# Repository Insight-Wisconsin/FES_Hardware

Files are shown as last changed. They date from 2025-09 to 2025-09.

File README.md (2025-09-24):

# FES_Hardware
Insight Wisconsin's FES R&amp;D team KiCad files

# Required Software:
**KiCad:** PCB layout and design software  
https://www.kicad.org/download/ (Select your OS and then the Github download)
 
**Git:** Version control software  
https://git-scm.com/downloads (Select your OS and then download at the top of the page)

(OPTIONAL)  
**WSL:** Linux command line on Windows  
Run powershell as admin and type wsl --install

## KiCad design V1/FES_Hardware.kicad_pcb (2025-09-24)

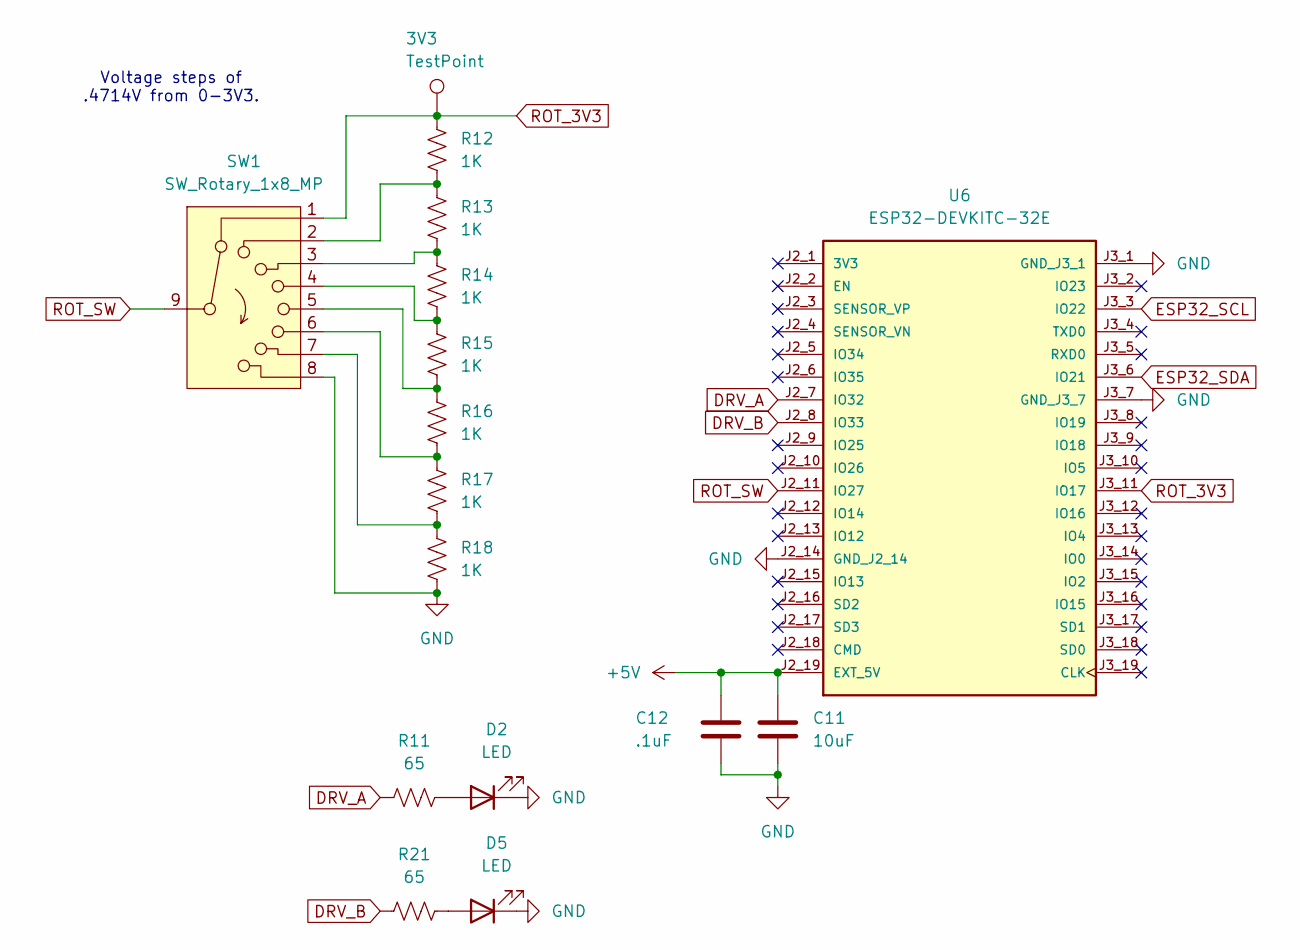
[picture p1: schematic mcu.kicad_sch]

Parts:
3V3: TestPoint; TestPoint_Keystone_5019_Minature
C11: 10uF; C_0805_2012Metric_Pad1.18x1.45mm_HandSolder
C12: .1uF; C_0805_2012Metric_Pad1.18x1.45mm_HandSolder
D2, D5: LED; LED_0805_2012Metric_Pad1.15x1.40mm_HandSolder
R11, R21: 65; R_0805_2012Metric_Pad1.20x1.40mm_HandSolder
R12, R13, R14, R15, R16, R17, R18: 1K; R_0805_2012Metric_Pad1.20x1.40mm_HandSolder
SW1: SW_Rotary_1x8_MP; 2925_ADA
U6: ESP32-DEVKITC-32E; MODULE_ESP32-DEVKITC-32E; PARTREV 1.4

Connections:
+5V: C11.1, C12.1, U6.J2_19 (EXT_5V); also elsewhere on the board
DRV_A: R11.1, U6.J2_7 (IO32); also elsewhere on the board
DRV_B: R21.1, U6.J2_8 (IO33); also elsewhere on the board
ESP32_SCL: U6.J3_3 (IO22); also elsewhere on the board
ESP32_SDA: U6.J3_6 (IO21); also elsewhere on the board
GND: C11.2, C12.2, D2.1 (K), D5.1 (K), R18.2, SW1.8, U6.J2_14 (GND_J2_14), U6.J3_1 (GND_J3_1), U6.J3_7 (GND_J3_7); also elsewhere on the board
unnamed: D2.2 (A), R11.2
unnamed: D5.2 (A), R21.2
unnamed: R12.2, R13.1, SW1.2
unnamed: R13.2, R14.1, SW1.3
unnamed: R14.2, R15.1, SW1.4
unnamed: R15.2, R16.1, SW1.5
unnamed: R16.2, R17.1, SW1.6
unnamed: R17.2, R18.1, SW1.7
ROT_3V3: 3V3.1, R12.1, SW1.1, U6.J3_11 (IO17)
ROT_SW: SW1.9, U6.J2_11 (IO27)

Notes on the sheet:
Voltage steps of .4714V from 0-3V3.

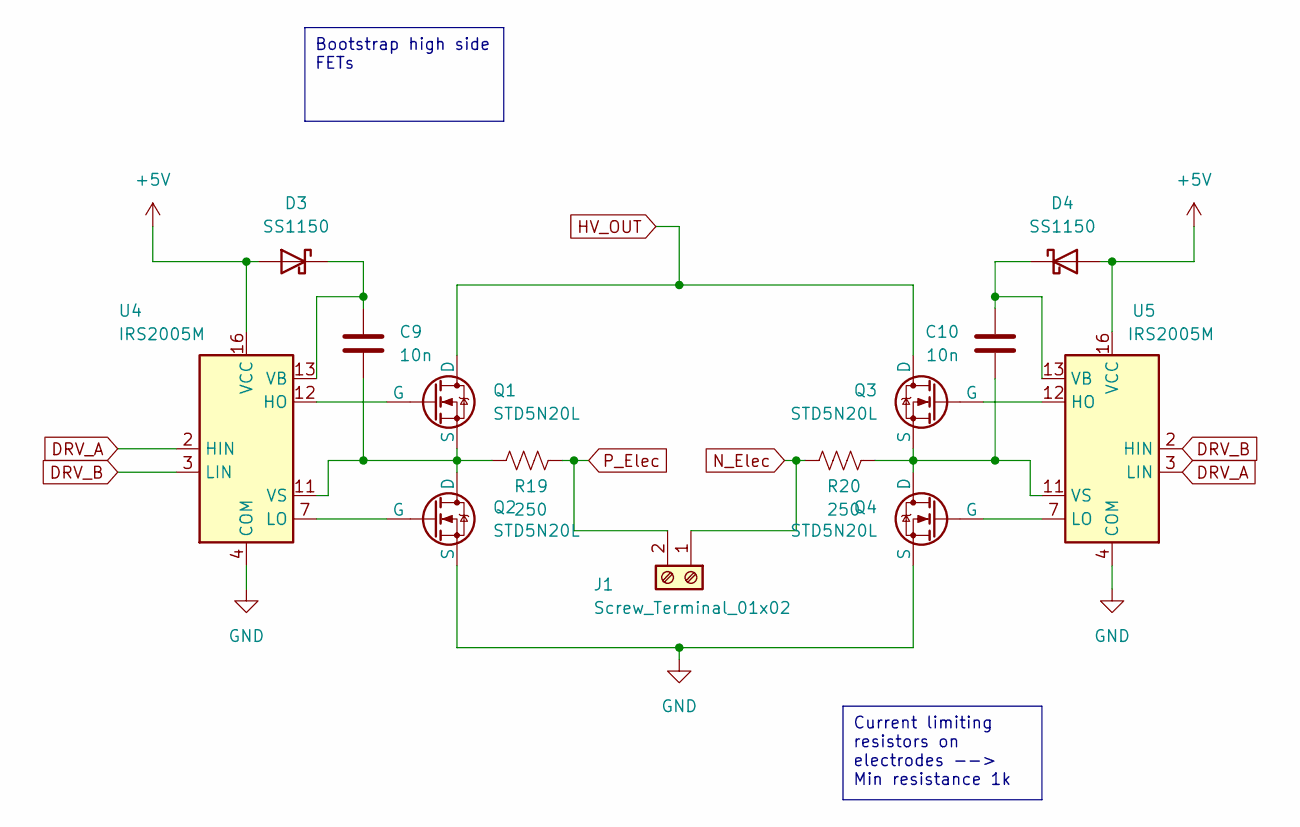
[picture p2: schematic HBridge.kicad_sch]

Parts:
C9, C10: 10n; C_0805_2012Metric_Pad1.18x1.45mm_HandSolder
D3, D4: SS1150; D_SMA
J1: Screw_Terminal_01x02; 691137710002
Q1, Q2, Q3, Q4: STD5N20L; STD5N
R19, R20: 250; R_0805_2012Metric_Pad1.20x1.40mm_HandSolder
U4, U5: IRS2005M; Infineon_MLPQ-16-14-1EP_4x4mm_P0.5mm

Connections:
+5V: D3.2 (A), D4.2 (A), U4.16 (VCC), U5.16 (VCC); also elsewhere on the board
DRV_A: U4.2 (HIN), U5.3 (LIN); also elsewhere on the board
DRV_B: U4.3 (LIN), U5.2 (HIN); also elsewhere on the board
GND: Q2.3 (S), Q4.3 (S), U4.4 (COM), U4.17 (COM), U5.4 (COM), U5.17 (COM); also elsewhere on the board
HV_OUT: Q1.1 (D), Q3.1 (D); also elsewhere on the board
N_Elec: J1.1, R20.1
unnamed: C9.1, D3.1 (K), U4.13 (VB)
unnamed: C10.1, D4.1 (K), U5.13 (VB)
unnamed: Q1.2 (G), U4.12 (HO)
unnamed: C9.2, Q1.3 (S), Q2.1 (D), R19.1, U4.11 (VS)
unnamed: Q2.2 (G), U4.7 (LO)
unnamed: Q3.2 (G), U5.12 (HO)
unnamed: C10.2, Q3.3 (S), Q4.1 (D), R20.2, U5.11 (VS)
unnamed: Q4.2 (G), U5.7 (LO)
P_Elec: J1.2, R19.2

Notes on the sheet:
Bootstrap high side FETs
Current limiting resistors on electrodes --> Min resistance 1k

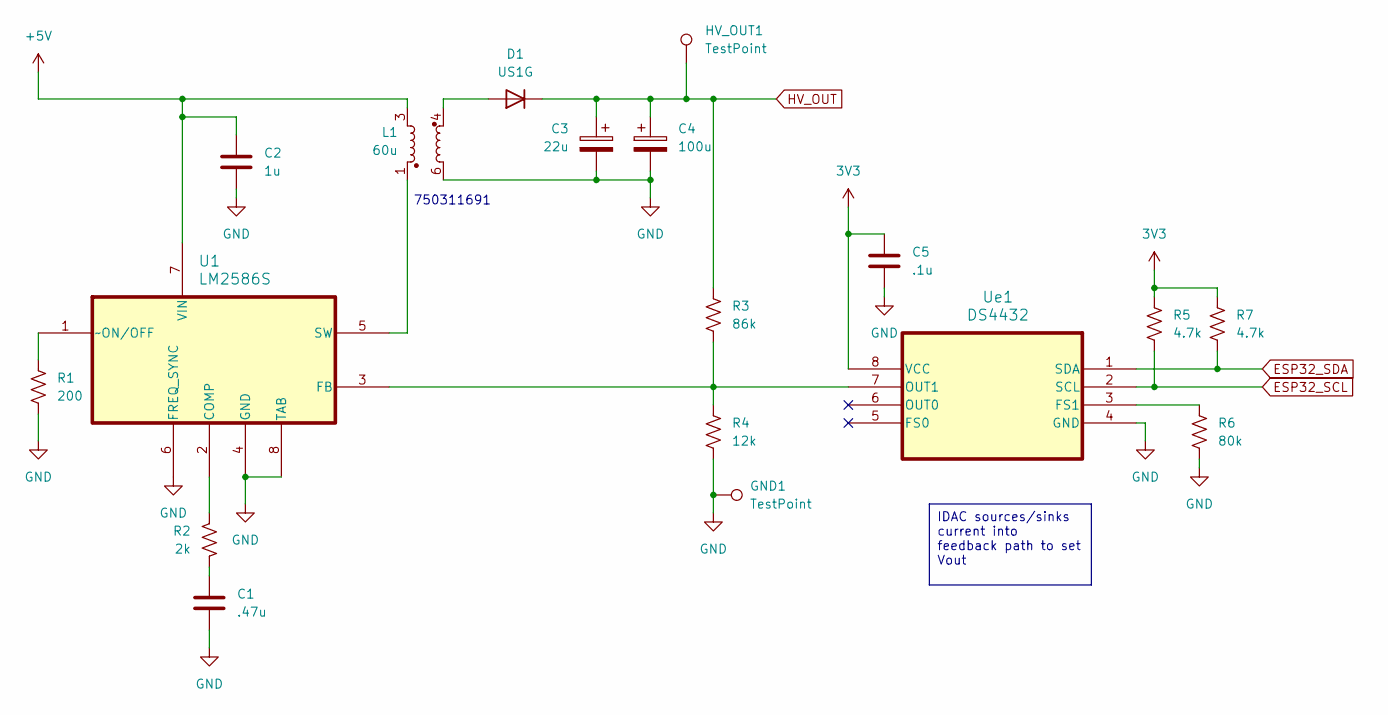
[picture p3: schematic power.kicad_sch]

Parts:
C1: .47u; C_0805_2012Metric_Pad1.18x1.45mm_HandSolder
C2: 1u; C_0805_2012Metric_Pad1.18x1.45mm_HandSolder
C3: 22u; C_0805_2012Metric_Pad1.18x1.45mm_HandSolder
C4: 100u; C_0805_2012Metric_Pad1.18x1.45mm_HandSolder
C5: .1u; C_0805_2012Metric_Pad1.18x1.45mm_HandSolder
D1: US1G; D_SMA
GND1: TestPoint; TestPoint_Keystone_5019_Minature
HV_OUT1: TestPoint; TestPoint_Keystone_5019_Minature
L1: 60u; WE 750311691
R1: 200; R_0805_2012Metric_Pad1.20x1.40mm_HandSolder
R2: 2k; R_0805_2012Metric_Pad1.20x1.40mm_HandSolder
R3: 86k; R_0805_2012Metric_Pad1.20x1.40mm_HandSolder
R4: 12k; R_0805_2012Metric_Pad1.20x1.40mm_HandSolder
R5, R7: 4.7k; R_0805_2012Metric_Pad1.20x1.40mm_HandSolder
R6: 80k; R_0805_2012Metric_Pad1.20x1.40mm_HandSolder
U1: LM2586S; TS7B
Ue1: DS4432; 21-0036_U8&plus_1_MXM

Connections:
3V3: C5.1, R5.1, R7.1, Ue1.8 (VCC)
+5V: C2.1, L1.3, U1.7 (VIN); also elsewhere on the board
ESP32_SCL: R5.2, Ue1.2 (SCL); also elsewhere on the board
ESP32_SDA: R7.2, Ue1.1 (SDA); also elsewhere on the board
GND: C1.2, C2.2, C3.2, C4.2, C5.2, GND1.1, L1.6, R1.2, R4.2, R6.2, U1.4 (GND), U1.6 (FREQ_SYNC), U1.8 (TAB), Ue1.4 (GND); also elsewhere on the board
HV_OUT: C3.1, C4.1, D1.1 (K), HV_OUT1.1, R3.1; also elsewhere on the board
unnamed: C1.1, R2.2
unnamed: D1.2 (A), L1.4
unnamed: R2.1, U1.2 (COMP)
unnamed: R3.2, R4.1, U1.3 (FB), Ue1.7 (OUT1)
unnamed: L1.1, U1.5 (SW)
unnamed: R1.1, U1.1 (~ON/OFF)
unnamed: R6.1, Ue1.3 (FS1)

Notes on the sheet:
IDAC sources/sinks current into feedback path to set Vout
750311691

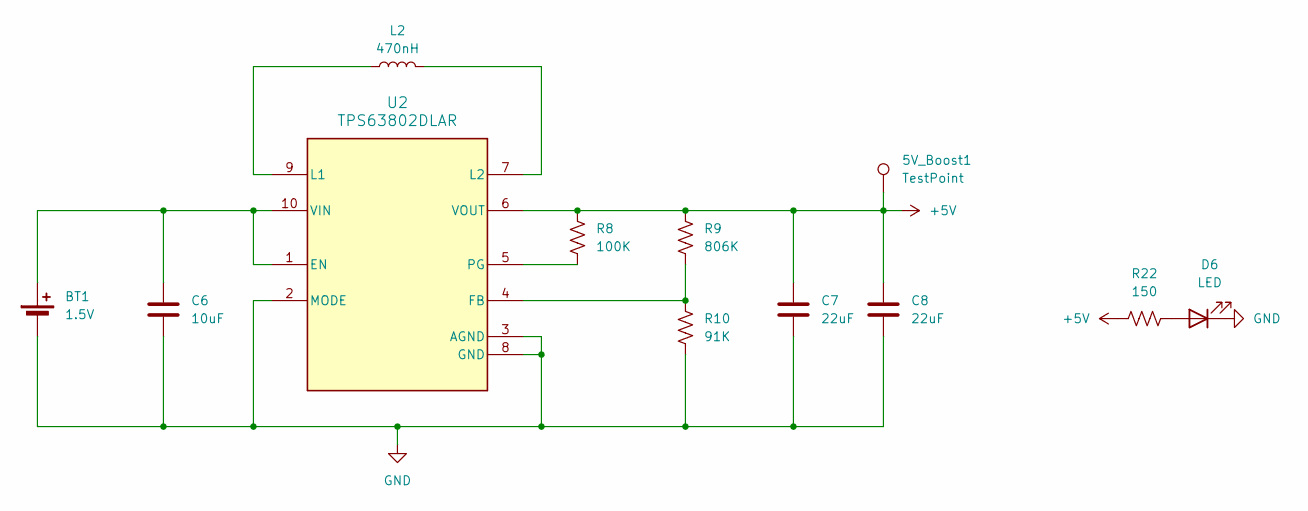
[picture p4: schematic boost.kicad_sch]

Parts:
5V_Boost1: TestPoint; TestPoint_Keystone_5019_Minature
BT1: 1.5V; BatteryHolder_Keystone_2460_1xAA
C6: 10uF; C_0805_2012Metric_Pad1.18x1.45mm_HandSolder
C7, C8: 22uF; C_0805_2012Metric_Pad1.18x1.45mm_HandSolder
D6: LED; LED_0805_2012Metric_Pad1.15x1.40mm_HandSolder
L2: 470nH; INDC2016X120N
R8: 100K; R_0805_2012Metric_Pad1.20x1.40mm_HandSolder
R9: 806K; R_0805_2012Metric_Pad1.20x1.40mm_HandSolder
R10: 91K; R_0805_2012Metric_Pad1.20x1.40mm_HandSolder
R22: 150; R_0805_2012Metric_Pad1.20x1.40mm_HandSolder
U2: TPS63802DLAR; DLA0010A

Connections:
+5V: 5V_Boost1.1, C7.1, C8.1, R8.2, R9.2, R22.1, U2.6 (VOUT); also elsewhere on the board
GND: BT1.2 (-), C6.2, C7.2, C8.2, D6.1 (K), R10.1, U2.2 (MODE), U2.3 (AGND), U2.8 (GND); also elsewhere on the board
unnamed: BT1.1 (+), C6.1, U2.1 (EN), U2.10 (VIN)
unnamed: D6.2 (A), R22.2
unnamed: R9.1, R10.2, U2.4 (FB)
unnamed: L2.1, U2.9 (L1)
unnamed: L2.2, U2.7 (L2)
unnamed: R8.1, U2.5 (PG)

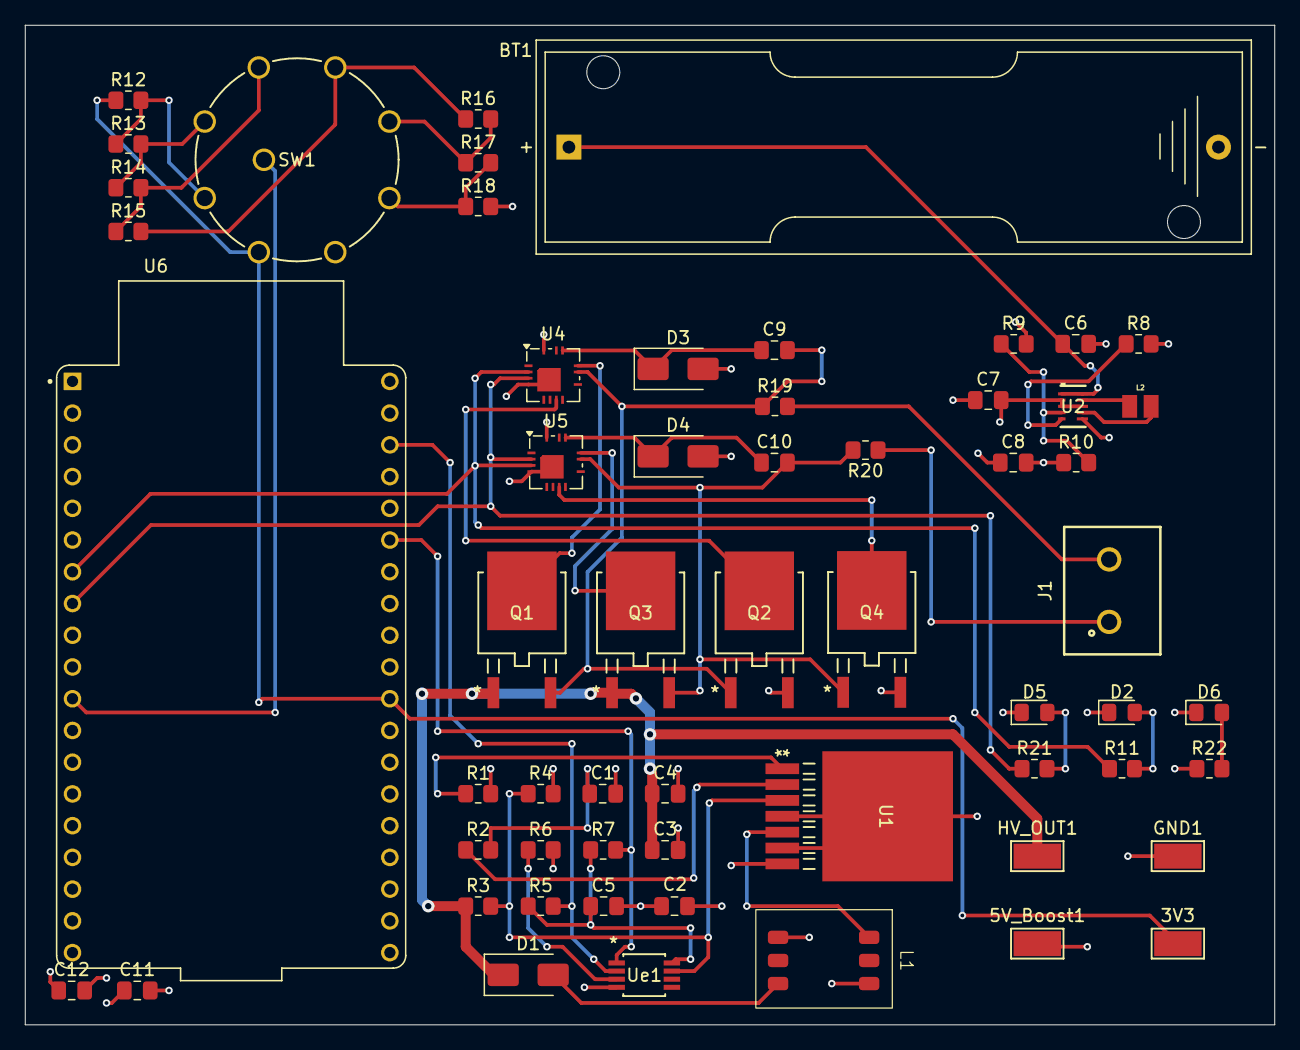
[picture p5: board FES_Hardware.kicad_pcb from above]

Board: 4 copper layers, 100.0 x 80.0 mm, 59 parts (0 on the bottom side), 41 nets.

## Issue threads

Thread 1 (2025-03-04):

Android Studio Documentation

rdrahozal, 2025-03-04:
# Gather any relevant documentation/tutorials on android app development.

**Relevant information may include:**

**XML Documentation:** Android Studio seems to use XML as their UI language. Research and brainstorm UI designs for the app and how to implement them.

**Android Sensor Integration:** Our app will need to get data from the phone's motion sensors. Investigate different APIs and packages that will allow us to do so.

**ESP32 Integration:** We will eventually need our app to communicate with the our ESP32 microcontroller to send electric pulses at the correct time. Research different methods we could achieve this integration/communication.

**Publishing:** Figure out how to publish our app to the Google Play Store.

**PUT ALL RELEVANT FILES OR LINKS IN THIS REPO'S WIKI**
(Make sure to add a relevant title and description)

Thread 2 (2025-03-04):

KiCad Documentation

rdrahozal, 2025-03-04:
# Gather any relevant documentation/tutorials on KiCad development in relation to the project

**Relevant information may include:**

**Working with KiCad:** We will be using KiCad to design and layout our PCBs. Find some documentation/tutorials on using KiCad.

**Working with electrodes:** We will be using electrodes to provide an electrical stimulation to leg muscles. Research different types of electrodes, different ways to integrate and connect them to the microcontroller, and ways to ensure they are safe.

**ESP32 Documentation:** We will be using the ESP32 microcontroller for this project. Research how to implement this microcontroller into a PCB layout, how to connect it, and any software needed to program it.

**PUT ALL RELEVANT FILES OR LINKS IN THIS REPO'S WIKI**
(Make sure to add a relevant title and description)

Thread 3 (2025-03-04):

PCB Design

rdrahozal, 2025-03-04:
# Design the PCB
The PCB will have to house the main components of the hardware side of the FES such as:

**Microcontroller:** Place the microcontroller and and required circuitry. The microcontroller will have to receive power  from the battery and then distribute signals to the electrodes to pulse depending on input from the app.

**Battery:** Implement a battery charging IC to recharge the battery when needed. The battery will have to supply power to the microcontroller and likely electrodes at accurate voltages. May need to implement buck/boost converters to adjust voltages.

**Electrodes:** Design how the electrodes will be connected and powered. Look online for viable electrodes to use and what voltages they require.

**REMEMBER SAFETY IS OUR HIGHEST PRIORITY**

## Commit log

2025-03-04 Initialized KiCad Project
    [FES_Hardware.kicad_pcb, FES_Hardware.kicad_sch]
2025-03-19 created individual project sheets
    [FES_Hardware.kicad_sch, boost.kicad_sch, mcu.kicad_sch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]
2025-03-27 Created 1v5 to 3v3 boost schematic for MCU
    [power.kicad_sch]
2025-03-29 Updated boost converter to output 5v instead of 3v3 for ESP32 dev board
    [power.kicad_sch]
2025-03-30 Moved 5v boost to the boost schematic
    [boost.kicad_sch, power.kicad_sch]
2025-04-01 Added HV schematic
    [power.kicad_sch]
2025-04-02 Created symbol/footprint for MCU & rotary encoder
    [mcu.kicad_sch]
2025-04-05 changed transformer, feedback resistors
    [power.kicad_sch]
2025-04-05 Finished rotary switch and updated MCU pinout
    [boost.kicad_sch, mcu.kicad_sch]
2025-04-08 Added H-Bridge, completed HV schematic
    [FES_Hardware.kicad_sch, power.kicad_sch]
2025-04-09 added H-Bridge sheet, symbols, footprints
    [HBridge.kicad_sch]
2025-04-09 updated symbols background to be transparent
    [power.kicad_sch]
2025-04-09 Updated references after merging
    [HBridge.kicad_sch, boost.kicad_sch, mcu.kicad_sch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]
2025-04-15 Updated footprints of passive elements to be 0805 Hand-Solder
    [HBridge.kicad_sch, boost.kicad_sch, mcu.kicad_sch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]
2025-04-16 added transformer and NMOS footprints
    [HBridge.kicad_sch, power.kicad_sch]
2025-04-16 added footprints
2025-04-16 Hopefully finalized schematic with footprints
    [HBridge.kicad_sch]
2025-04-16 Final schematic design for PCB layout hopefully
2025-04-16 Didn't save, my bad-final schematic
    [mcu.kicad_sch]
2025-04-16 Started initial KiCad layout
    [FES_Hardware.kicad_pcb]
2025-04-17 routed PCB and added status LED for 5V
    [FES_Hardware.kicad_pcb, mcu.kicad_sch]
2025-04-17 ryanPCB branch commit for pcb layout
    [FES_Hardware.kicad_pcb]
2025-04-17 commiting unsaved changes
    [boost.kicad_sch]
2025-04-23 tidied up PCB routing, renamed HV_OUT, changed MCU footprint/schematic
    [FES_Hardware.kicad_pcb, HBridge.kicad_sch, mcu.kicad_sch]
2025-04-29 added decoupling caps to MCU 5V input
    [FES_Hardware.kicad_pcb, mcu.kicad_sch]
2025-09-24 Organized V1 files
    [FES_Hardware.kicad_pcb, FES_Hardware.kicad_sch, HBridge.kicad_sch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]
